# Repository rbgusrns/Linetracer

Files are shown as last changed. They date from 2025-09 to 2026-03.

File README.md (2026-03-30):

<div align="center">

# Linetracer
### Award-winning domestic competition line tracing robot platform

An integrated line tracing robot project that combines race firmware, control electronics, PCB data, and mechanical assets in a single repository.

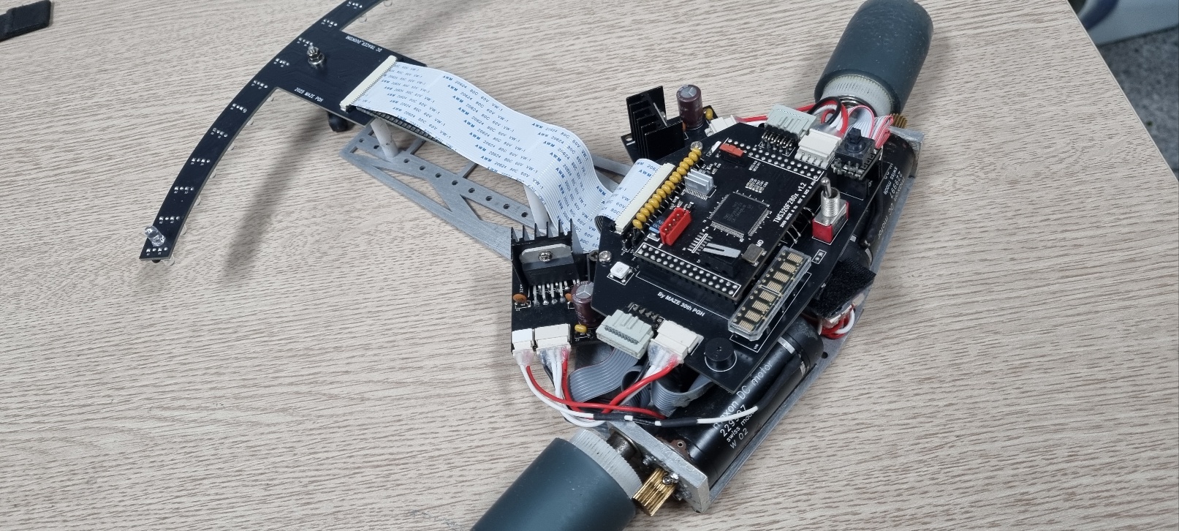
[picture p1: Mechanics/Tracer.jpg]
Linetracer robot photo


<br />






</div>

---

## Overview

`Linetracer` is a high-speed autonomous line tracing robot built for major domestic competition tracks in Korea. Like `JP_Robotrace`, this repository is not limited to firmware alone. It also preserves PCB design assets, logic references, mechanical models, manufacturing data, and supporting monitor firmware, making it a complete engineering archive rather than a source-only project.

At its core is a TI C2000-based control platform tuned for aggressive line following, sensor-driven motion control, and repeatable race setup. The repository captures both the competition robot itself and the surrounding hardware and tooling required to build, inspect, and maintain it.

---

## Competition History

This robot platform was developed for domestic line tracing competitions in Korea and achieved top awards across multiple events.

- **Grand Prize** - 20th National Intelligent Robot Competition
- **Grand Prize** - 26th National Line Tracer Contest
- **Excellence Award** - 14th Robot Fusion Festival

Those results position `Linetracer` as an award-winning competition robot archive, documenting a platform that was proven on real race tracks rather than only in development environments.

---

## Gallery

<table>
  <tr>
    <td width="50%">
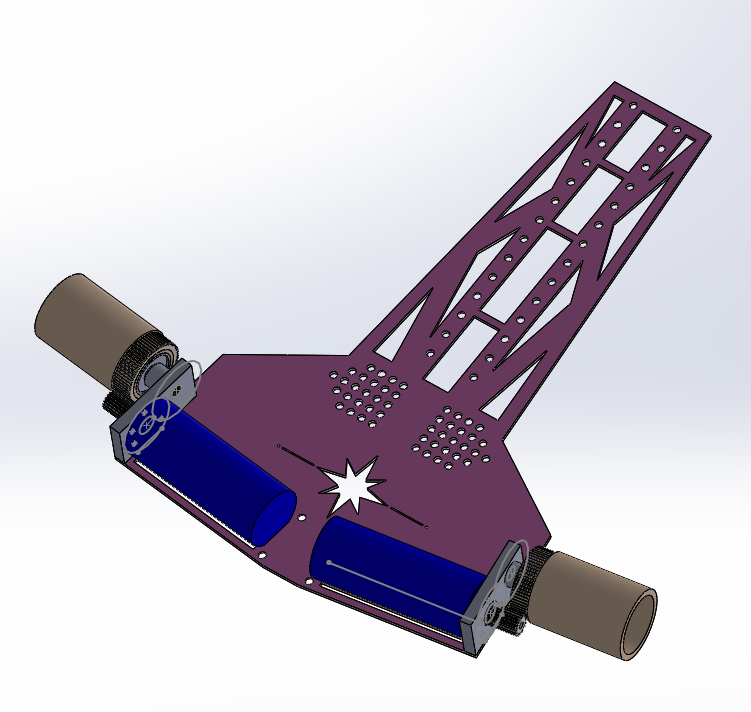
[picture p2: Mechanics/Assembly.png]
Assembly model
      
    </td>
    <td width="50%">
      Robot photo
    </td>
  </tr>
  <tr>
    <td width="50%">
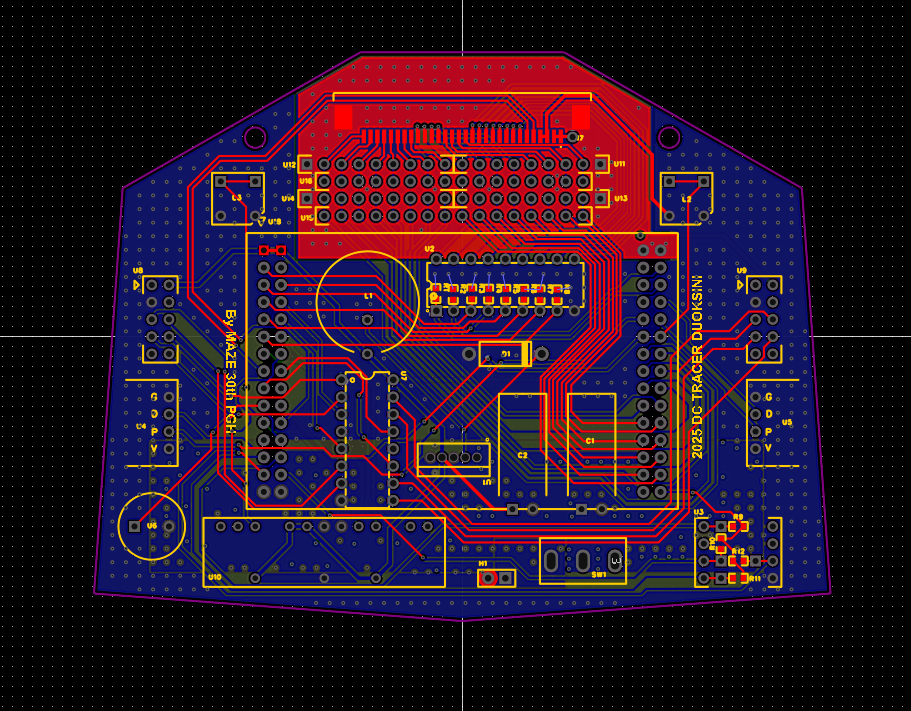
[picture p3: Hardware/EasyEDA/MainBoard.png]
Main board
      
    </td>
    <td width="50%">
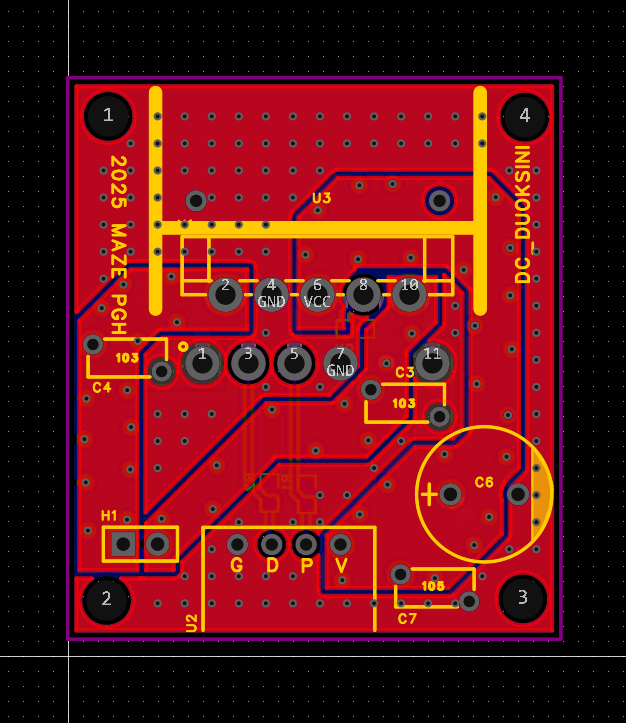
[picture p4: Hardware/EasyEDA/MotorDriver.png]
Motor driver board
      
    </td>
  </tr>
</table>

<p align="center">
  <sub>Competition hardware, mechanical design, and board-level implementation are preserved together in one repository.</sub>
</p>

---

## Key Features

- High-speed line tracing firmware built for domestic competition environments
- Multiple run profiles including search, fast run, extreme run, and bril run
- Closed-loop control using sensor input, motor feedback, and dedicated DSP support code
- Separate monitor firmware for inspection, flash handling, and display-oriented tooling
- Hardware resources including EasyEDA projects, PADS sensor board data, logic PDFs, and Gerber outputs
- Mechanical assets including assembly visuals, robot photography, and printable STL models

---

## Project Structure

```text
Linetracer/
├── Docs/                    # Component documents and technical references
├── Hardware/                # PCB design data, board images, Gerbers, and logic docs
│   ├── EasyEDA/
│   ├── Gerber/
│   ├── Logic/
│   └── PADS/
├── Mechanics/               # Mechanical assets, photos, and STL models
│   └── STL/
└── Software/                # Race firmware and monitoring firmware
    ├── _Vistan_/
    └── monitor_2809/
```

---

## Software Layout

The main race-oriented source lives under `Software/_Vistan_/main/`, where the firmware is organized around direct embedded functionality instead of layered abstractions. Important files visible in the project include:

- `main.c` - system initialization and runtime control entry point
- `Motor.c` - motor drive and motion control logic
- `sensor.c` - line sensor processing
- `search.c` - search-oriented driving behavior
- `fastrun.c` - high-speed tracing mode
- `extremerun.c` - aggressive race profile
- `brilrun.c` - top-end performance run mode
- `menu.c` - local configuration and menu flow
- `flash.c` - flash-related handling
- `VFD.c` - display output control
- `LS7166.c` - external counter or encoder-related handling

The repository also includes a separate `Software/monitor_2809/` project with its own build flow and files such as `flash.c`, `LCD.c`, and `VFD.c`, which suggests a dedicated monitoring or support firmware used alongside the main racer platform.

From the shipped makefiles, the firmware targets include `a_Vistan` and `a_DOUKSINI`, and the codebase is built around a TI C2000 toolchain layout with Source Insight-era project artifacts still preserved.

---

## Hardware

This repository also captures the electrical and manufacturing side of the robot.

- `Hardware/EasyEDA/` contains editable board projects and preview images for the main board and motor driver
- `Hardware/PADS/` contains sensor board layout data and image assets
- `Hardware/Logic/` contains circuit reference PDFs for the main board, motor driver, and sensor board
- `Hardware/Gerber/` preserves manufacturing-ready outputs

That combination makes the repository useful for rebuilding the robot electronics, not only for reading the firmware.

---

## Mechanical Assets

The `Mechanics/` directory includes both presentation material and fabrication-oriented assets.

- `Assembly.png` shows the chassis and mounting layout as a CAD-style assembly
- `Tracer.jpg` captures the real competition robot with exposed electronics and front sensor structure
- `STL/` stores printable or reference geometry such as `BaseBoard.STL`, `Wheel.STL`, `Gear.STL`, `Pinion.STL`, and `RE25_MotorGuard.STL`

This makes the repository valuable for understanding both the robot architecture and the practical mechanical packaging used in competition.

---

## Technology Snapshot

| Category | Details |
|---|---|
| MCU Family | Texas Instruments `TMS320F2808` / `TMS320F2809` |
| Firmware Language | `C`, `Assembly` |
| Editor | Source Insight |
| Build Configuration | TI C2000-oriented make flow |
| Build Targets | `a_Vistan`, `a_DOUKSINI` |
| Repository Scope | Firmware, PCB, Gerber, STL, logic docs, component references |

---

## Run Modes and Support Tools

Based on the preserved source layout, the project includes several competition driving strategies as well as supporting maintenance tools.

- **Search** for line acquisition and controlled recovery
- **Fast Run** for higher-speed race operation
- **Extreme Run** for aggressive performance tuning
- **Bril Run** for an additional top-end driving profile
- **Monitor Firmware** for flash, LCD, and VFD-centered support workflows

This split suggests a development workflow that separated race execution from monitoring, setup, or maintenance utilities.

---

## Build Notes

The repository contains source, project files, and make configuration, but it does not yet provide a modern step-by-step setup guide.

What can be verified from the repository:

- The project is built around a TI C2000 embedded platform
- `Software/_Vistan_/main/MAKEFILE` identifies the target as `a_Vistan`
- `Software/monitor_2809/main/MAKEFILE` identifies the target as `a_DOUKSINI`
- The source tree preserves an IAR- and Source Insight-era embedded workflow

What is still undocumented:

- Exact flashing procedure for each firmware target
- Required debugger, programmer, or download environment
- Board assembly and wiring sequence
- Parameter tuning flow for different tracks and competitions

---

## Why This Repository Is Interesting

Many line tracing repositories preserve only code or only hardware snapshots. `Linetracer` is interesting because it keeps the full competition story together: race firmware, monitor utilities, board design data, mechanical assets, and a documented award history from domestic competitions.

For anyone studying high-speed line tracers, DSP-based embedded control, or full-stack robot competition workflows, this repository is a compact record of how a proven Korean competition robot was designed and maintained.

---

## Credits

From the primary race firmware make configuration:

- **Author:** Yuk Keun Ho
- **Company:** MAZE

---

## License

This repository does not currently include a standalone license file. Add one if you want to make reuse terms explicit.

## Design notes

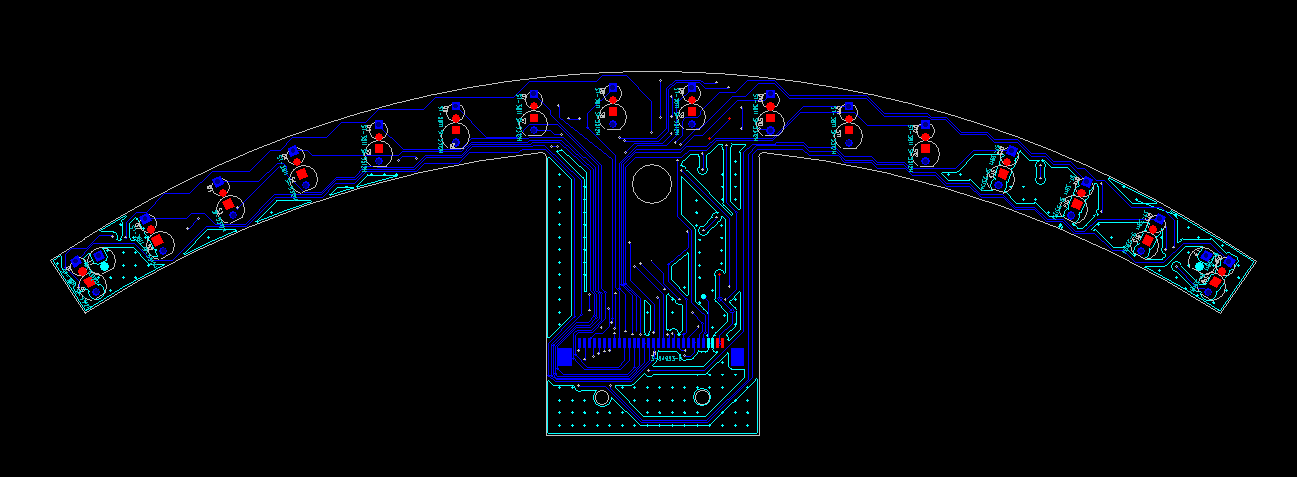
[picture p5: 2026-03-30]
Hardware/PADS/SensorBoard.png

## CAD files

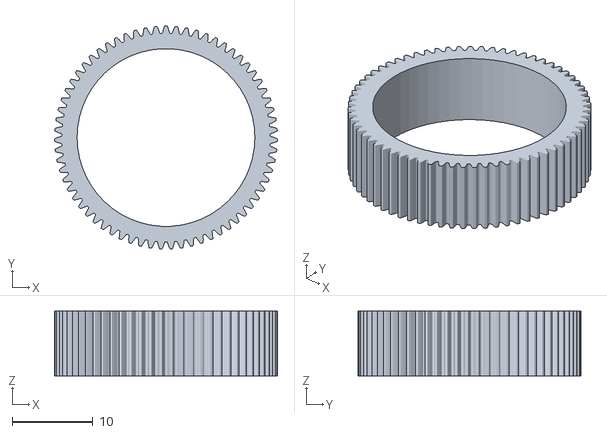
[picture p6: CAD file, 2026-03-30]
Mechanics/STL/Gear.STL
27.6 x 27.6 x 8.00

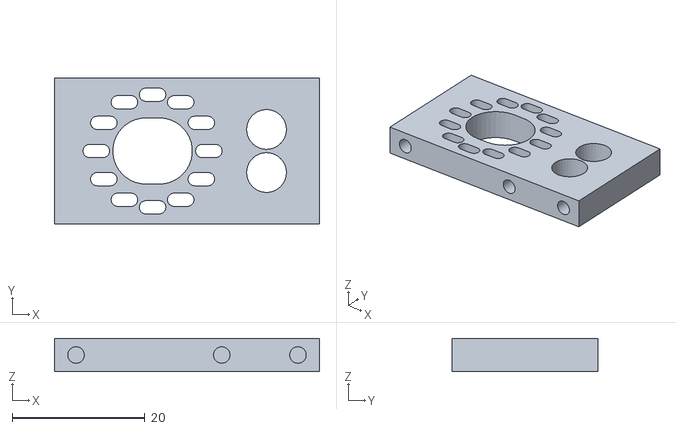
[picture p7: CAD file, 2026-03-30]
Mechanics/STL/RE25_MotorGuard.STL
40.0 x 22.0 x 5.00

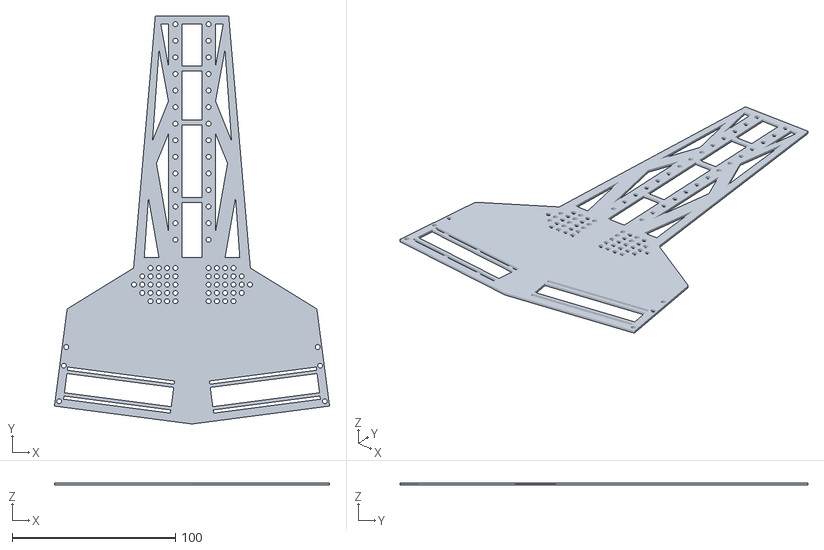
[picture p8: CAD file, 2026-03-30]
Mechanics/STL/BaseBoard.STL
168.6 x 250.0 x 1.50

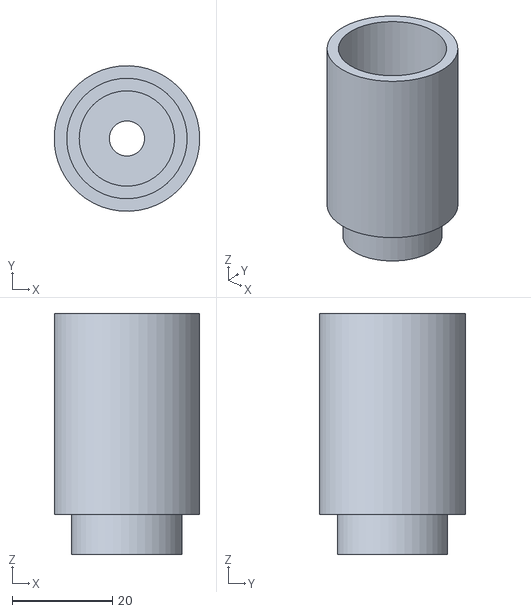
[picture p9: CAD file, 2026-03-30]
Mechanics/STL/Wheel.STL
29.0 x 29.0 x 48.0

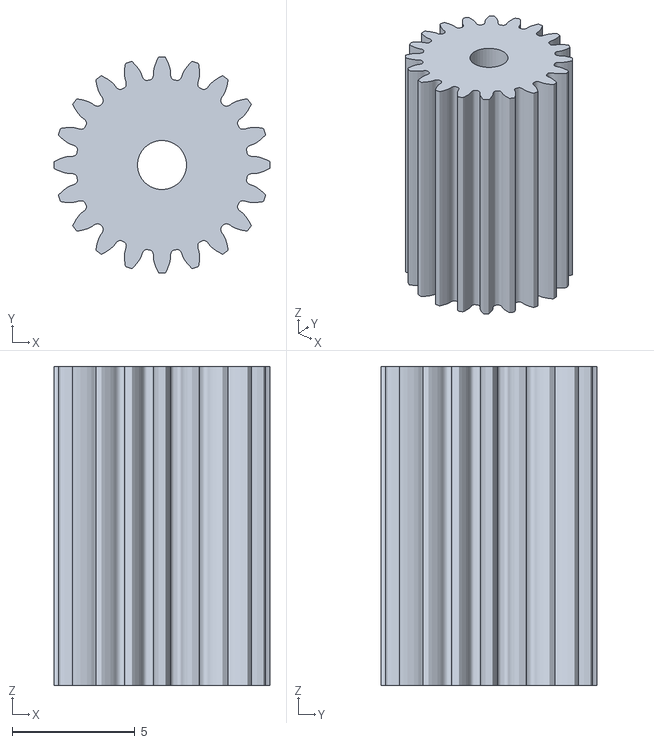
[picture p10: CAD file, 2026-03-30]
Mechanics/STL/Pinion.STL
8.80 x 8.80 x 13.0

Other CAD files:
Software/monitor_2809/main/main.obj
Software/_Vistan_/main/main.obj
Software/_Vistan_/main/DSP280x_CpuTimers.obj
Software/monitor_2809/main/DSP280x_DefaultIsr.obj
Software/_Vistan_/main/search.obj
Software/monitor_2809/main/DSP280x_CpuTimers.obj
Software/_Vistan_/main/DSP280x_EQep.obj
Software/monitor_2809/main/DSP280x_usDelay.obj
Software/_Vistan_/main/DSP280x_usDelay.obj
Software/monitor_2809/main/DSP280x_PieVect.obj
Software/_Vistan_/main/menu.obj
Software/monitor_2809/main/VFD.obj
Software/_Vistan_/main/DSP280x_Spi.obj
Software/_Vistan_/main/DSP280x_Adc.obj
Software/_Vistan_/main/DSP280x_CodeStartBranch.obj
Software/_Vistan_/main/DSP280x_DefaultIsr.obj
Software/_Vistan_/main/DSP280x_EPwm.obj
Software/_Vistan_/main/DSP280x_GlobalVariableDefs.obj
Software/_Vistan_/main/DSP280x_Gpio.obj
Software/_Vistan_/main/DSP280x_MemCopy.obj
Software/_Vistan_/main/DSP280x_PieCtrl.obj
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

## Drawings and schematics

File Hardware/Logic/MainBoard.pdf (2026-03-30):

# Power

# 3A 10 3Y 11 G# 12 4Y 13 4A 14 4B 15 VCC 16

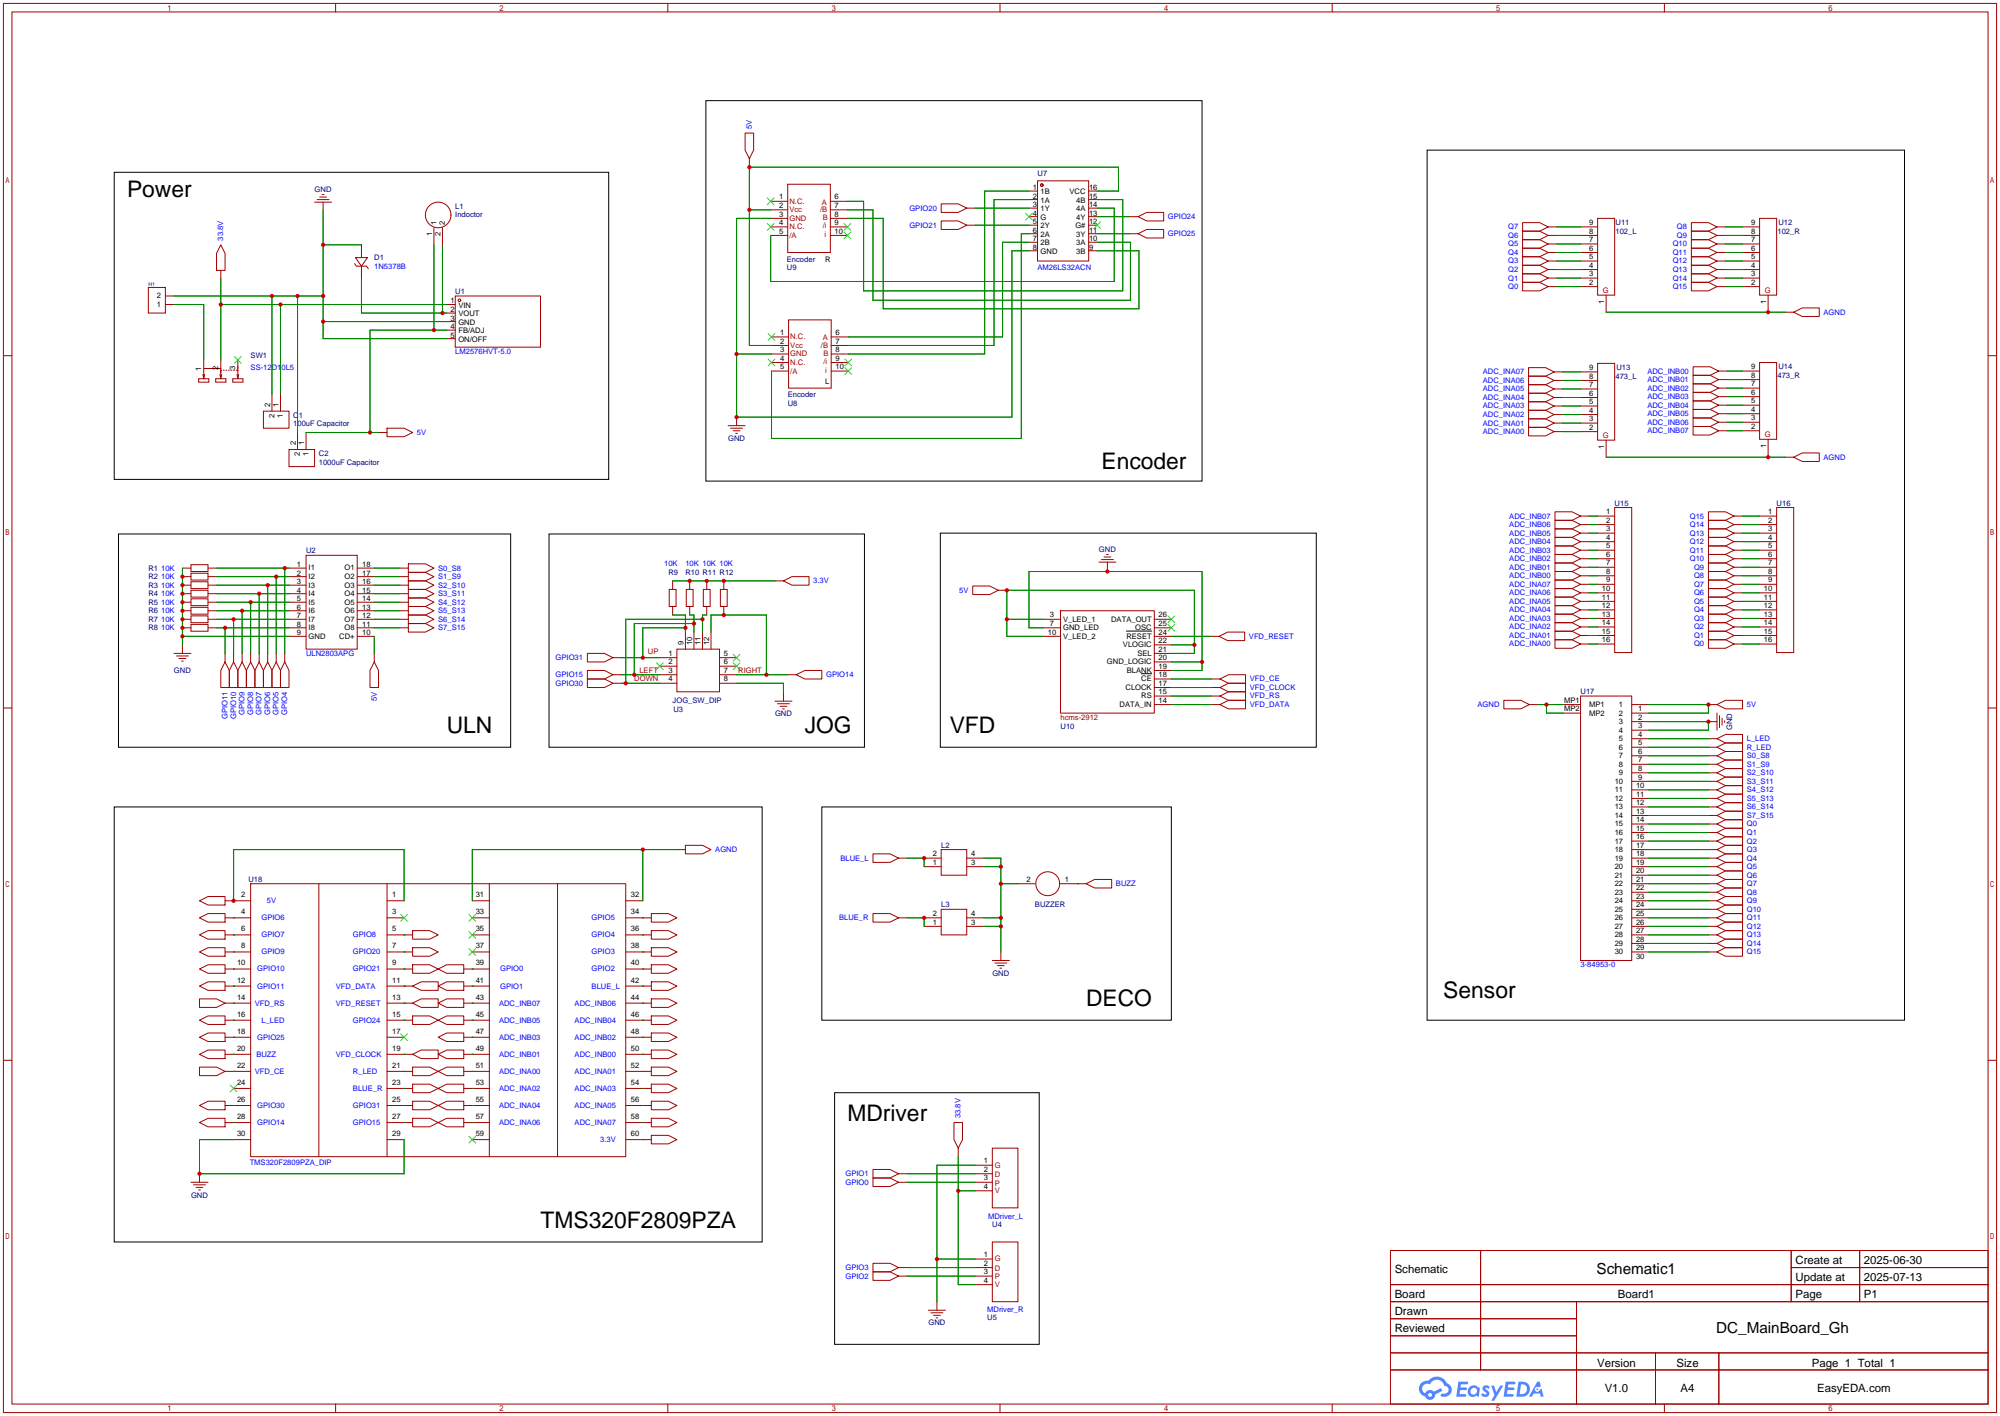
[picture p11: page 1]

DATA_IN 14 RS 15 CLOCK 17 CE 18 BLANK 19 GND_LOGIC 20 SEL 21 VLOGIC 22 RESET 24 OSC 25 DATA_OUT 26

Schematic | Schematic1 | Create at | 2025-06-30

Update at | 2025-07-13

Board | Board1 | Page | P1
Drawn | | DC_MainBoard_Gh
Reviewed

Version | Size | Page 1 Total 1
V1.0 | A4 | EasyEDA.com

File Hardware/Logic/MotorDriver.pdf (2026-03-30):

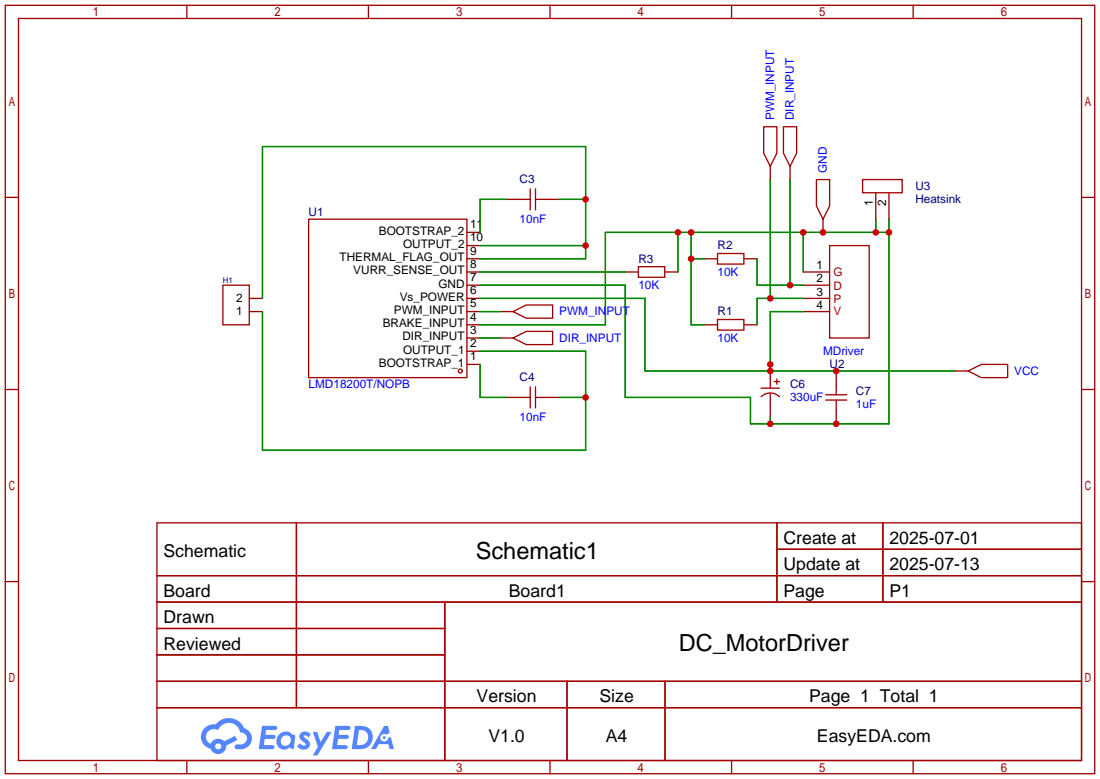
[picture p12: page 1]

Schematic | Schematic1 | Create at | 2025-07-01

Update at | 2025-07-13

Board | Board1 | Page | P1
Drawn | | DC_MotorDriver
Reviewed

Version | Size | Page 1 Total 1
V1.0 | A4 | EasyEDA.com

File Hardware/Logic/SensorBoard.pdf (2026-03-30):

# ABCD

6

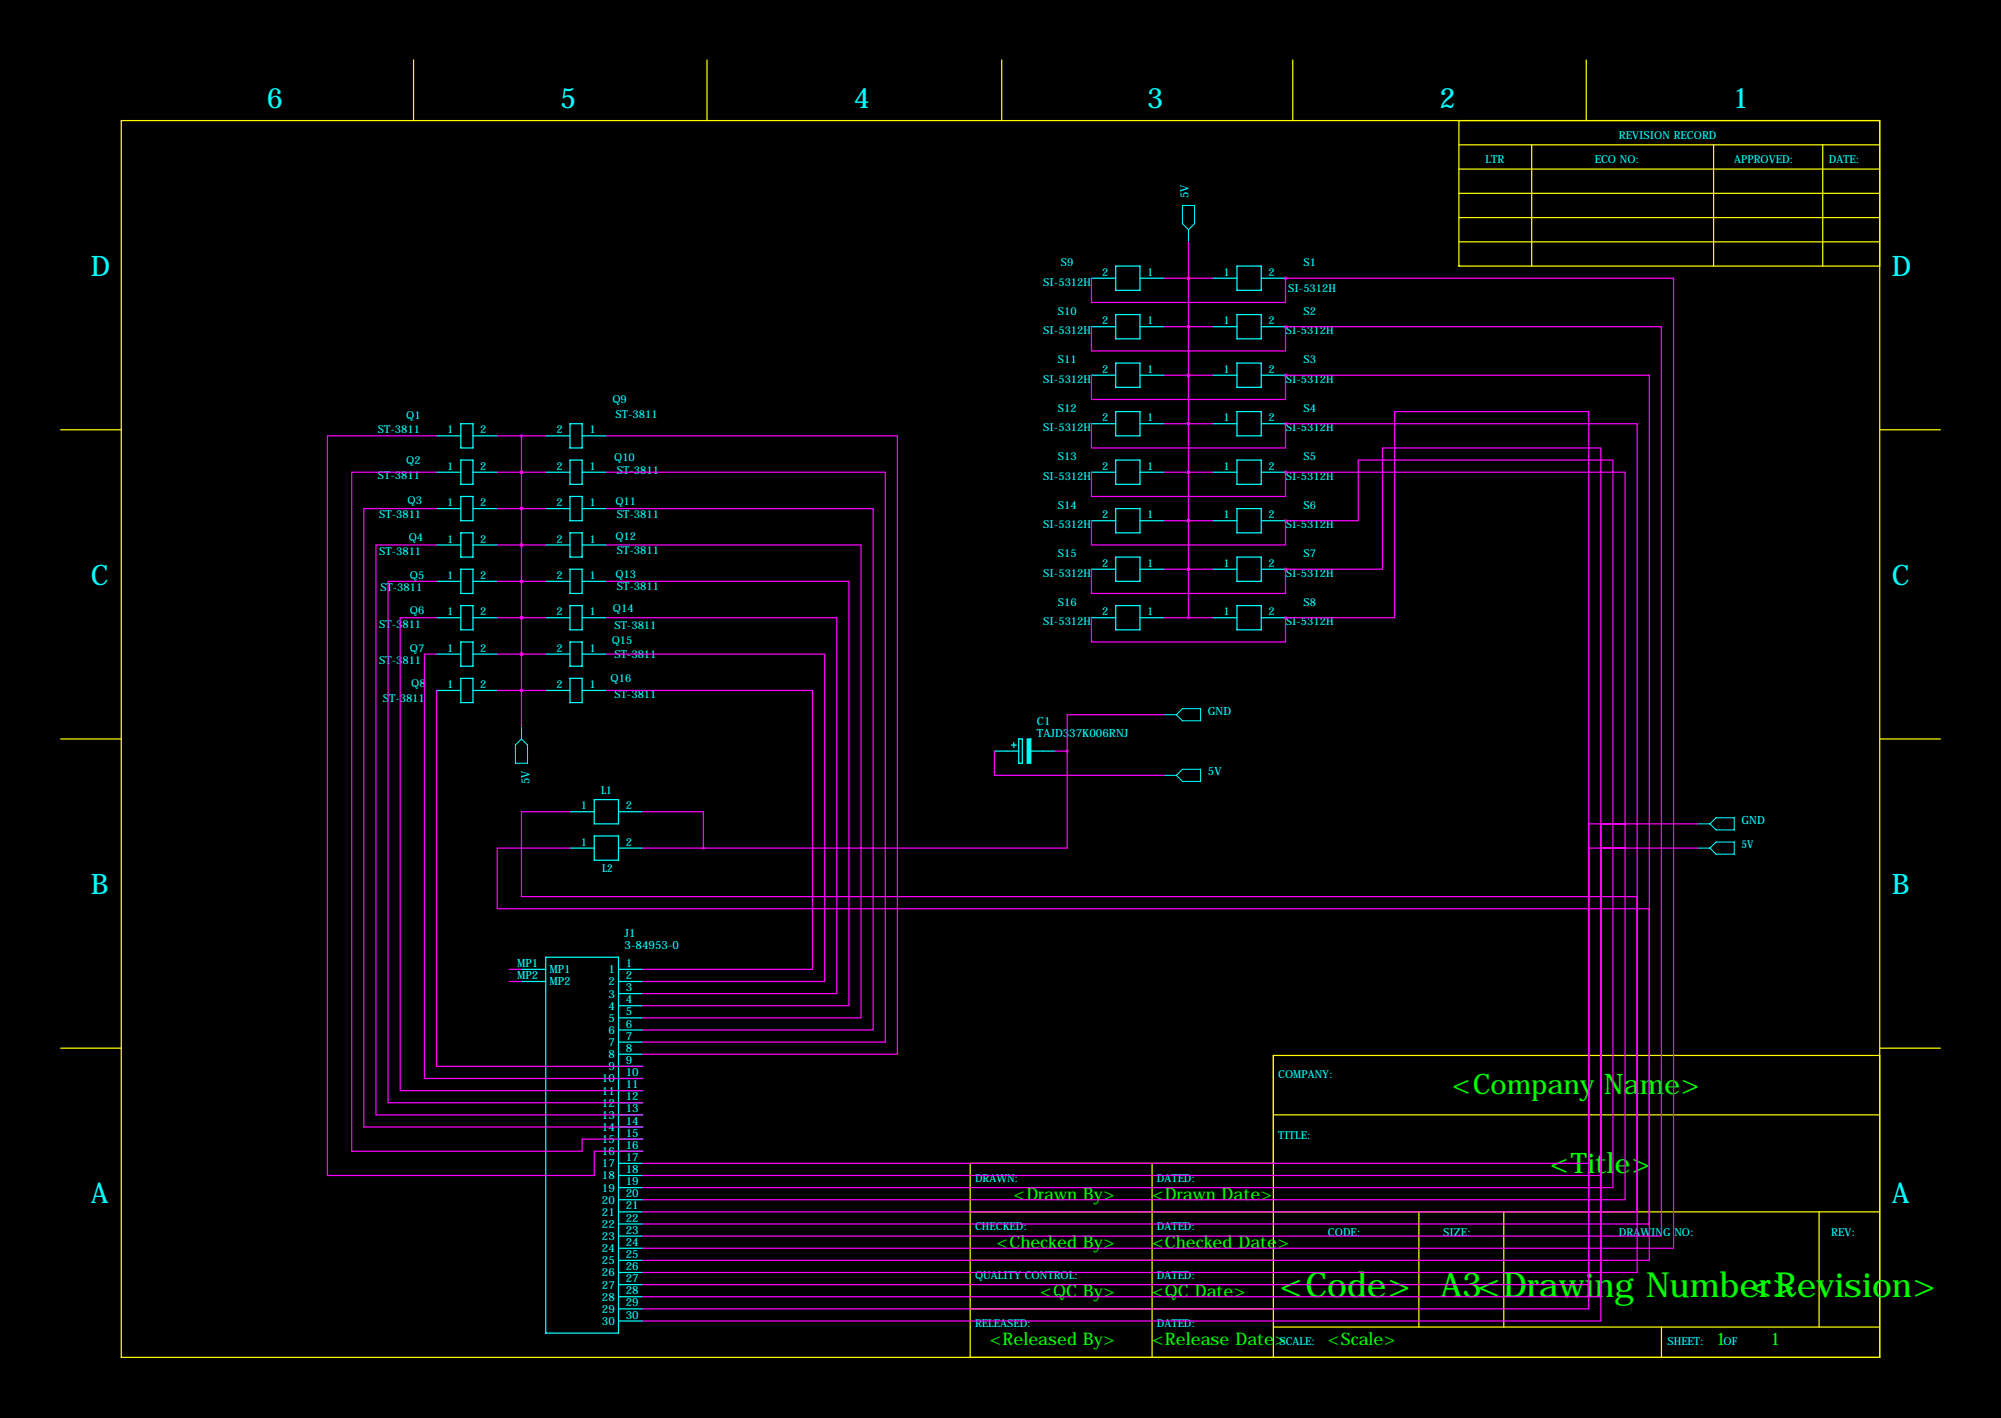
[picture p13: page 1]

REVISION RECORD

LTR | ECO NO: | APPROVED: | DATE:

DRAWN: | DATED:
<Drawn By> | <Drawn Date>

CHECKED: | DATED: | CODE: | SIZE:
<Checked By> | <Checked Date>

REV:

QUALITY CONTROL: | DATED:

<QC By> | <QC Date>

RELEASED: <Released By> | DATED:

<Scale> SCALE: | 1 1 SHEET: OF

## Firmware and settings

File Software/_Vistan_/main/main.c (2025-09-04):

#define _MAIN_
#define __STRUCT__

#include "DSP280x_Device.h"     // DSP281x Headerfile Include File
#include "DSP280x_Examples.h"  // DSP281x Examples Include File

void System_Init(void)
{
	DINT;				// 전체 인터럽트 금지
	InitSysCtrl();		// 워치록 금지, PLL 초기화, 주변 장치 클럭설정
	InitGpio();			// 입출력 포트 초기화	
	InitCpuTimers();
	
	MemCopy(&RamfuncsLoadStart, 	&RamfuncsLoadEnd, 	&RamfuncsRunStart); 
	MemCopy(&RamfuncsLoadStart1, 	&RamfuncsLoadEnd1, 	&RamfuncsRunStart1);
	
	InitSci();			
	InitSpi();
	InitPieCtrl();		// PIE 제어 레지스터 초기화 동작
	IER = 0x0000;		// 인터럽트 인에이블 레지스터 클리어
	IFR = 0x0000;		// 인터럽트 플래그 레지스터 클리어
	InitPieVectTable();
	InitAdc();

	Init_ISR();

	InitEPWM( &LeftPwmRegs );
	InitEPWM( &RightPwmRegs );
	
	InitEQep( &LeftQepRegs );
	InitEQep( &RightQepRegs );
}

void Variable_Init( void )
{
	
	memset( ( void * )&g_Flag , 0x00 , sizeof( bit_field_flag_t ) );
	memset( ( void * )g_sen , 0x00 , sizeof( sen_t) * 16 );
	memset( ( void * )&g_pos, 0x00 , sizeof( position_t ) );
	memset( ( void * )&g_rmark, 0x00 , sizeof( turnmark_t ) );
	memset( ( void * )&g_lmark, 0x00 , sizeof( turnmark_t ) );
	memset( ( void * )g_ptr , 0x00 , sizeof( str_point_t * ) );
	memset( ( void * )&g_line_info , 0x00 , sizeof(lineinfo_t) );
	memset( ( void * )&g_run_info , 0x00 , sizeof(runinfo_t) * 256 );
	memset( ( void * )g_fast_info , 0x00 , sizeof(fast_run_str) * 256 );
	memset( ( void * )&g_err, 0x00, sizeof( error_str ) );

    g_q28kp = _IQ28(0.42);
	g_q28kd = _IQ28(0.62);
//  g_q28kp = _IQ28(0.80);
//	g_q28kd = _IQ28(0.85);

    
	motor_vari_init(&g_rm);
	motor_vari_init(&g_lm);
	
	sen_vari_init();

	g_ptr = &g_ptemp;
	g_ptr->g_lmark = &g_lmark;
	g_ptr->g_rmark = &g_rmark;
	g_ptr->pfastinfo = g_fast_info;
	g_ptr->perr = &g_err;


	g_int32senmode_cnt = 0;
	g_int32accmode_cnt = 0;
	g_int32tmode_cnt = 0;
	g_int32lineout_cnt = 0;
	g_int32mark_cnt = 0;
	g_int32total_cnt = 0;
	g_q17user_vel_2000 =_IQ(0);

	g_int32err_cnt = 0;
	g_int32dist = 0;

    
	g_float32time_cnt = 0.0;
	g_int32timer_cnt = 0;

	g_q17turnmark_dist = _IQ(70);
	//g_q17turnmark_dist = _IQ(146);
	g_q17cross_dist = _IQ(0);
	g_u16turnmark_limit = 100;
	//g_u16turnmark_limit = 95;
	g_q17sen_valmax = _IQ(50);

	/*position pid value*/
	g_pos.iq7kp = POS_KP_UP; // 1.5
	g_pos.iq7ki = _IQ7(0.008);
	g_pos.iq7kd = POS_KD_UP; // 4.4
	
	/*sensor value*/
	g_u16sen_enable = 0;
    g_u16pos_cnt = S_SIX;
    g_u16sen_state = 0;

	g_int32_sen_cnt = 0;
    g_int32_sen2_cnt = 0;
	g_int32_full_cnt = 0;
	g_int32speed_up_cnt = 0;   

	//
	g_q17straight_dist  = _IQ17(0); // extreme run 
	g_q17shift_dist = _IQ17(0);

	g_q17right_handle = _IQ(1);
	g_q17left_handle = _IQ(1);


	g_q17user_acc = _IQ(13000);
    g_int32decel = 15000; //가속보다 감속을 더하자 .. 감속도 고정 !
	g_q17end_acc = _IQ(12500); // _IQ(13500)
	g_q17endturn_acc = g_q17user_acc;
	g_q17fast_vel_limit = _IQ(7700);
	//g_q17sec_end_vel = _IQ(2300);

	g_q17user_vel = _IQ(2300); // search run vel
 	
	//g_q17large_vel = _IQ(3200);
	
	g_q17large_vel = _IQ(3000);
	g_q17large_acc = _IQ(5000); // large turn accel  
	g_q17limit_vel = _IQ17(0);   

	g_q16han_decmax = _IQ16(0);
	g_q16han_accmax = _IQ16(0);
	g_q16han_decstep = _IQ16(0);
	g_q16han_accstep = _IQ16(0);
	
	g_q16right_handle_temp = _IQ16(1);
	g_q16left_handle_temp = _IQ16(1);	

	////////////////////////////////////handle_search//////
	g_q16out_corner_limit = _IQ16(0.400);	//0.15			
	//0.3//0.24	//0.55	//0.6	
	g_q16in_corner_limit = _IQ16(2.600);		//3.0
	//3.1//2.6	//1.7	//1.6
	////////////////////////////////////////////////

	////////////////////////////////////handle_fast///////
	g_q16out_corner_fast_limit = _IQ16(0.400);		
	//0.20	//0.21	//0.45	//0.4
	
	g_q16in_corner_fast_limit = _IQ16(2.600);		
	//3.31	//3.1	//1.9	//2.0c 
	////////////////////////////////////////////////
	
	turn_step = _IQ7( 3.0 );
	g_line_info.u16cross_total_cnt = 0;

	/*	extremerun variables	*/
	g_int32shift_level=4;
	g_q17end_vel = _IQ(2200);
	g_q17end_dist = _IQ(100);
	
	g_q1745user_vel = _IQ(3500);
    g_q1790user_vel = _IQ(3500);

	g_q17_45acc = _IQ(8000);
	g_q17_45vel = _IQ(7000); // g_q1745user_vel 


	g_q17ext_large_vel = g_q17user_vel + _IQ(VEL_LARGE);
	g_q17ext_large_acc = _IQ(3000); // large turn accel  
	
	g_q17max_acc = g_q17user_acc;
	g_q17mid_acc = g_q17user_acc;
	g_q17short_acc = g_q17user_acc + _IQ(2000);
	
	g_q17s4s_vel = _IQ(3300);
	g_q17s44s_vel = _IQ(4000); 
	g_q17escape45_vel = _IQ(3500);
	 
	g_q7shift_pos = _IQ7(0.0);
	g_q17shift_pos_val = _IQ(0.0);
	g_q7shift_pos_val = _IQ7(0.0); 

	g_int32ext_mode_cnt = 3;		// 90도 연속 + 큰턴가속 x
	g_int32fasterror_flag = 1;
	i=0;

    g_q17shift_ratio = _IQ(7);
    g_q17return_ratio = _IQ(8);
    g_q17st_ret_ratio = _IQ(4);


}

void main(void)
{	
	System_Init();
	Variable_Init();
    race_start_init();
	VfdInit();
	
	

	///초기값 설정//
	MOTOR_TIMER_ENABLE; // start cputimer1 
	
    VFDPrintf("LOADING|");
	maxmin_read_rom();
    turnvel_read_rom();    
    acc_info_read_rom();
    handle_read_rom();
    VFDPrintf("LOADING/");
    turnmark_info_read_rom();
	cross_info_read_rom();
	mark_read_rom();
    VFDPrintf("LOADING-");
    extvel_read_rom();
    VFDPrintf("LOADING\\");
	fast_infor_read_rom();
    
    
	//g_Flag.motor_start = ON;
	//move_to_end(_IQ(100), _IQ(0), g_q17end_acc);
	
    	
	LEFT_LED_OFF;
	RIGHT_LED_OFF;

	LEFT_BLUE_OFF;
    
	RIGHT_BLUE_OFF;

	BUZZ_OFF;

	TxPrintf("%5f, %5F\n", _IQ16toF(HANDLE_CENTER / 250) , _IQ16toF(_IQ16div(HANDLE_CENTER, _IQ16(250)) ) );
	TxPrintf("PULSE_TO_V: %10f\n",_IQ25toF(_IQ25( 33.37209546898672 )));
	menu_start();

	while( 1 )
	{
		

        /************************************************************************************************************************************\
        *                                                                                                                                    *
        *                                                                                                                                    *
        *                                                                                                                                    *
        *             _/_/_/    _/_/    _/      _/  _/_/_/    _/_/_/_/  _/      _/  _/_/_/    _/_/_/  _/_/_/_/_/    _/_/    _/      _/       *
        *          _/        _/    _/  _/_/    _/  _/    _/  _/        _/      _/    _/    _/            _/      _/    _/  _/_/    _/        *
        *           _/_/    _/_/_/_/  _/  _/  _/  _/    _/  _/_/_/    _/      _/    _/      _/_/        _/      _/_/_/_/  _/  _/  _/         *
        *              _/  _/    _/  _/    _/_/  _/    _/  _/          _/  _/      _/          _/      _/      _/    _/  _/    _/_/          *
        *       _/_/_/    _/    _/  _/      _/  _/_/_/    _/_/_/_/      _/      _/_/_/  _/_/_/        _/      _/    _/  _/      _/           *
        *                                                                                                                                    *
        *                                                                                                                                    *                                                                                                                                   *                                                                                                                                   
        *                                                                                                                                    *                                     
        *                                                                                                                                    *                                        
        \************************************************************************************************************************************/  
        //TxPrintf("L: %d\tR: %d\n",g_lm.int16qep_val ,g_rm.int16qep_val);
        //TxPrintf("L: %ld\tR: %ld\n",g_lm.q17cur_vel_avr >> 17 ,g_rm.q17cur_vel_avr >> 17);
        //GpioDataRegs.GPACLEAR.bit.GPIO3 = 1;
		//
		//RightPwmRegs.CMPA.half.CMPA =100;
		//GpioDataRegs.GPASET.bit.GPIO1 = 1;
		//LeftPwmRegs.CMPA.half.CMPA = 100;
	}
}

void Delay(Uint32 Cnt)
{
	while(Cnt--)
	{
		asm("		nop");
		
		asm("	nop");
	}
}  


void print_second_info()
{    
	int i=0;
	for( i=0; i<256;i++)
	{
		
							TxPrintf("%d| dst: %5d| dec: %5ld| mdst: %5ld| turn_dir: 0x%04X| acc: %5ld| in: %5ld| vel: %5ld| out: %5ld| cnt: %d | down: %d| s44s: %d| escape: %d| kp: %.2f| RDIST: %ld| LDIST: %ld| P: %ld\n",
									i,
										  g_fast_info[ i ].u16dist,
													g_fast_info[ i ].q17dec_dist>>17,	
															  g_fast_info[ i ].q17m_dist>>17,
																		 g_fast_info[ i ].u16turn_dir,																 
																						g_fast_info[ i ].q17acc>>17,
																								 	g_fast_info[ i ].q17in_vel>>17,
																								 		 			g_fast_info[ i ].q17vel>>17,
																								 							 g_fast_info[ i ].q17out_vel>>17,
																								 							 g_fast_info[ i ].u16turn_cnt,
																								 							 g_fast_info[ i ].down_flag,
																								 							 g_fast_info[ i ].s44s_flag,
																								 							 g_fast_info[ i ].escape_flag,
																								 							 _IQ7toF(g_fast_info[ i ].q7kp_val),
																								 							 g_fast_info[ i ].q17r_dist>>17,
																								 							 g_fast_info[ i ].q17l_dist>>17,
																								 							 g_fast_info[ i ].iq7pos_integral_val>>7
																								 							 );
							if(i==g_int32total_cnt){
								TxPrintf("-----------------------------------\n");
							}
							else if(i== g_int32total_cnt + 5){
								break;
							}
							else;
	}
}

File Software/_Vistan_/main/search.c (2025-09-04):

//###########################################################################
//
// FILE		: search.c
//
// TITLE		: gungun_v2 Tracer fastrun source file.
//
// Author	: Park geon ju
//
// Company	: MAZE
//
//###########################################################################
// $Release Date: 2015.11.21 $
//###########################################################################


#include "DSP280x_Device.h"     // DSP280x Headerfile Include File
#include "DSP280x_Examples.h"   // DSP280x Examples Include File

#if 0
void line_information (turnmark_t *pmark)
{
	if(!g_Flag.fast_flag )										//search
	{
		g_line_info.u16line_dist[g_line_info.u16turnmark_total_cnt] = IQ_TO_UINT16(g_lm.q17total_dist);
		
		if( g_ptr->g_lmark == pmark )
			g_line_info.u16RL_Info[g_line_info.u16turnmark_total_cnt] = LEFT;
		else
			g_line_info.u16RL_Info[g_line_info.u16turnmark_total_cnt] = RIGHT;

	//	TxPrintf("[%u] :%u \n",g_line_info.u16turnmark_total_cnt ,g_line_info.u16line_dist[g_line_info.u16turnmark_total_cnt]);
		
		g_line_info.u16turnmark_total_cnt++;
	}
	
	else if( g_Flag.fast_flag && !g_Flag.debug_flag )
	{
		g_line_info.u16turnmark_total_cnt++;
		g_Flag.speed_up_flag = OFF;
	
		if( _IQabs( g_lm.q17total_dist - _IQ(g_line_info.u16line_dist[ g_line_info.u16turnmark_total_cnt-1 ]) ) > _IQ(500) )
		{
		//	DEBUG_LED_ON;
			g_Flag.debug_flag = ON;
		}

		if (g_line_info.u16turn_Info[ g_line_info.u16turnmark_total_cnt ] == STRAIGHT )
		{
			g_Flag.speed_up_flag = ON;
		//	STRAIGHT_LED_ON;
			//if(g_line_info.u16line_dist[ g_line_info.u16turnmark_total_cnt ] > 700)
			if( g_line_info.u16turnmark_total_cnt == g_line_info.u16turnmark_final_cnt )
			{

				move_to_move(_IQ(g_line_info.u16line_dist[ g_line_info.u16turnmark_total_cnt ]),_IQ(g_line_info.u16decel_dist[ g_line_info.u16turnmark_total_cnt ]) , 
					g_run_info[g_line_info.u16turnmark_total_cnt].q17in_vel, _IQ(2000), g_run_info[g_line_info.u16turnmark_total_cnt].q17acc );

			}
			else
			{
				move_to_move(_IQ(g_line_info.u16line_dist[ g_line_info.u16turnmark_total_cnt ]),_IQ(g_line_info.u16decel_dist[ g_line_info.u16turnmark_total_cnt ]) , 
					g_run_info[g_line_info.u16turnmark_total_cnt].q17in_vel, g_run_info[g_line_info.u16turnmark_total_cnt].q17out_vel, g_run_info[g_line_info.u16turnmark_total_cnt].q17acc );

			}
			
		}
	
		
	}
	else if ( g_Flag.debug_flag )
		g_line_info.u16turnmark_total_cnt++;

	else;
	g_lm.q17total_dist = g_rm.q17dist_sum = g_lm.q17dist_sum = _IQ(0);
}


#endif

void line_info(turnmark_t *pmark)
{
	if( pmark == NULL) // end 거리 
	{
		g_fast_info[g_int32mark_cnt].q17l_dist = g_lm.q17end_gone_distance;
		g_fast_info[g_int32mark_cnt].q17r_dist = g_rm.q17end_gone_distance;
	}
	else // 나머지 
	{
		g_fast_info[g_int32mark_cnt].q17l_dist = g_lm.q17gone_distance;
		g_fast_info[g_int32mark_cnt].q17r_dist = g_rm.q17gone_distance;
	}
	
	g_lm.q17gone_distance = g_rm.q17gone_distance = _IQ17(0);
	if( pmark == NULL) g_fast_info[g_int32mark_cnt].u16turn_way = ETURN; // end
	
	
	g_fast_info[g_int32mark_cnt].u16dist = IQ_TO_UINT16( ( g_fast_info[g_int32mark_cnt].q17l_dist >> 1 ) + ( g_fast_info[g_int32mark_cnt].q17r_dist >> 1 ) ); // 마크와 마크 사이 거리 
	g_fast_info[g_int32mark_cnt].iq7pos_integral_val = g_pos.iq7integral_val;

    g_pos.iq7integral_val = _IQ7(0.0);
	//TxPrintf("1\n");
	g_int32mark_cnt++;
	g_fast_info[g_int32mark_cnt].u16turn_way = ( pmark == g_ptr->g_lmark ) ? ( RTURN ) : ( LTURN );	// left or right 
		
	if( g_int32mark_cnt && g_fast_info[g_int32mark_cnt].u16turn_way == g_fast_info[g_int32mark_cnt - 1].u16turn_way )
		g_fast_info[g_int32mark_cnt].u16turn_way = STRAIGHT;  // straight
//	g_lm.q17total_dist = g_rm.q17dist_sum = g_lm.q17dist_sum = _IQ(0);
    //VFDPrintf("%8d",g_fast_info[g_int32mark_cnt].u16turn_way);
}


void turn_info_func( void )
{
	int32 i = 0;
	for( i = 0; i <= g_int32total_cnt; i ++ )
	{
		turn_info_compute( &g_fast_info[ i ], i);
		
	}
}


void turn_info_compute( fast_run_str *pinfo, int32 mark_cnt )
{ 
	int32 temp = 0;
	_iq17 max = _IQ17(0), min = _IQ17(0);
	
	g_q17user_vel_2000 = _IQ17div(g_q17user_vel,_IQ17(2000)); // ????
	
	if( !mark_cnt ) pinfo->u16turn_way = STRAIGHT;	//출발(무조건 직진) 

	if( ( pinfo->u16turn_way & STRAIGHT ) && !( pinfo->u16turn_way & ETURN) )	//이미 직진임이 판단난 경우(마지막 구간 제외)
	{                                                                           // 직진인데 마지막 턴 아님 
		pinfo->u16turn_dir = STRAIGHT;
		pinfo->u16turn_cnt = D_STR;	// 직진 가속시 사용 -> 자세보정 후 가속할 수 있도록 카운터 적용 (speed_up_function)
		
		if( mark_cnt )
		{
			if( pinfo->u16dist > SHORT_DIST ) // dist > 400
			{    //                    직진 거리- 현재 턴속* D_X * 500ms = 실제 가속할 거리 
				//temp = (int32)(pinfo->u16dist) - (int32)((_IQmpy( _IQmpy(g_q17user_vel, _IQ(( pinfo - 1 )->u16turn_cnt )), _IQ17(0.0005))) >> 17);
				temp = (int32)(pinfo->u16dist) - (int32)((_IQmpy(g_q17user_vel_2000 ,_IQ17( ( pinfo - 1 )->u16turn_cnt )))>>17);
				//윗줄 확인 요망
				if( temp <= 0 ) // 딜레이거리가 직진보다 큼 
				{
					temp = (int32)(pinfo->u16dist);
					( pinfo - 1 )->u16turn_cnt = D_STR; 
				}
			}
			else // 최소 직진 거리보다 낮음 
			{
				temp = (int32)(pinfo->u16dist);
				( pinfo - 1 )->u16turn_cnt = D_STR;	
			}
		
			pinfo->u16dist = (Uint16) temp;	//잰 거리를가속할 거리로 변경 	
		}
	}
	else if( !( pinfo->u16turn_way & STRAIGHT ) && !( pinfo->u16turn_way & ETURN ) ) 	//Default TURN
	{
		if( pinfo->u16dist <= TURN_45_DIST )	//45
		{
			pinfo->u16turn_dir = TURN_45 | pinfo->u16turn_way;
			pinfo->u16turn_cnt = ( ( pinfo + 1 )->u16turn_way & STRAIGHT )? D_45A : D_STR; //다음 구간이 직진이면 45, 아니면 STR.
		}
		else if( pinfo->u16dist > TURN_45_DIST && pinfo->u16dist <= TURN_90_DIST ) //90 
		{
			pinfo->u16turn_dir = TURN_90 | pinfo->u16turn_way;
			pinfo->u16turn_cnt = ( ( pinfo + 1 )->u16turn_way & STRAIGHT )? D_90A : D_STR;
            //if( ( ( pinfo - 1 )->u16turn_way & STRAIGHT ) && ( ( pinfo + 1 )->u16turn_way & STRAIGHT ) ) 
            //    pinfo->u16turn_cnt = D_90A - 10;
		}
		else if( pinfo->u16dist > TURN_90_DIST && pinfo->u16dist <= TURN_180_DIST )	//180
		{
			pinfo->u16turn_dir = TURN_180 | pinfo->u16turn_way;
			pinfo->u16turn_cnt= ( ( pinfo + 1 )->u16turn_way & STRAIGHT )? D_180A : D_STR;
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

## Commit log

2025-06-27 20250627 default
    [DSP280x_Adc.obj, DSP280x_CodeStartBranch.obj, DSP280x_CpuTimers.obj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]
2025-07-26 led,buzz off
    [DSP280x_Adc.obj, DSP280x_CodeStartBranch.obj, DSP280x_CpuTimers.obj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]
2025-08-04 fix 90acc
    [DSP280x_Adc.obj, DSP280x_CodeStartBranch.obj, DSP280x_CpuTimers.obj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]
2025-08-14 switch motor
    [DSP280x_Adc.obj, DSP280x_CodeStartBranch.obj, DSP280x_CpuTimers.obj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]
2025-08-15 motor bibration
    [DSP280x_Adc.obj, DSP280x_CodeStartBranch.obj, DSP280x_CpuTimers.obj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]
2025-08-15 시립대 대회
    [DSP280x_Adc.obj, DSP280x_CodeStartBranch.obj, DSP280x_CpuTimers.obj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]
2025-08-16 시립대 1st
    [DSP280x_Adc.obj, DSP280x_CodeStartBranch.obj, DSP280x_CpuTimers.obj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]
2026-03-30 add folder
    [BaseBoard.STL, DSP280x_Adc.obj, DSP280x_CodeStartBranch.obj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]
